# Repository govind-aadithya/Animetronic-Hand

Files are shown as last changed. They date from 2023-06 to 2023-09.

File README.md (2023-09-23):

# Animatronic-Hand

## Objective
Gesture-controlled animatronic hand intended to perform teleoperation. 

The project was developed as a proof of concept for teleoperation using gesture tracking.

## Purpose
This was a concept developed for a Hardware Hackathon "Byte into Hardware" held at NJIT in April'23. The theme of the hackathon was to empower accessibility for differently abled. 

## Hardware
1. 3D Printed Animatronic Hand
2. Tower Pro Servos (SG90)
3. Logitech Web Cam
4. Arduino
5. IMU - MPU6050.

## Approach
The project uses Computer Vision to perform gesture tracking and interpret the gestures made by the user. This is then sent to the Arduino as actuation commands to make the Animatronic hand replicate the gesture.
To complete the loop, we used a Logitech webcam to provide a video feed to the user by coupling it with servos for yaw control. The command to the yaw control is given via an IMU that tracks the yaw of the user's head.

### Architecture
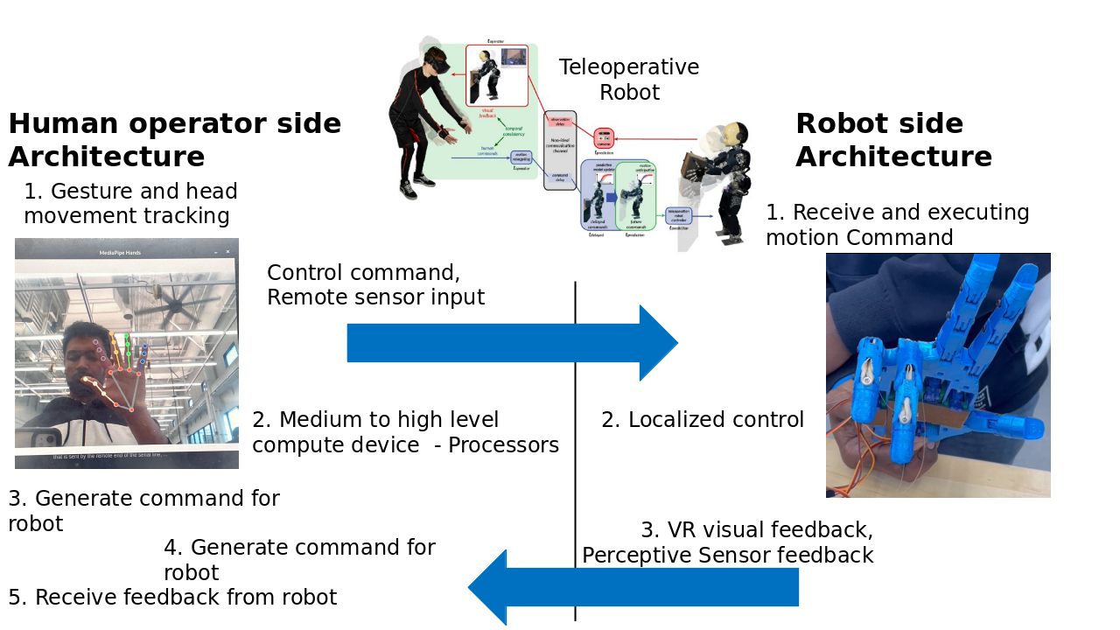
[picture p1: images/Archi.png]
Architecture


## Animatronic Hand
The .stp file was developed and printed on an Ultimaker 3D Printer. Since on slicing the file, the print duration was over 48hrs, the print was spit in several parts and printed on multiple printers.
The files can be found in the [CAD folder](./CAD) of the project.

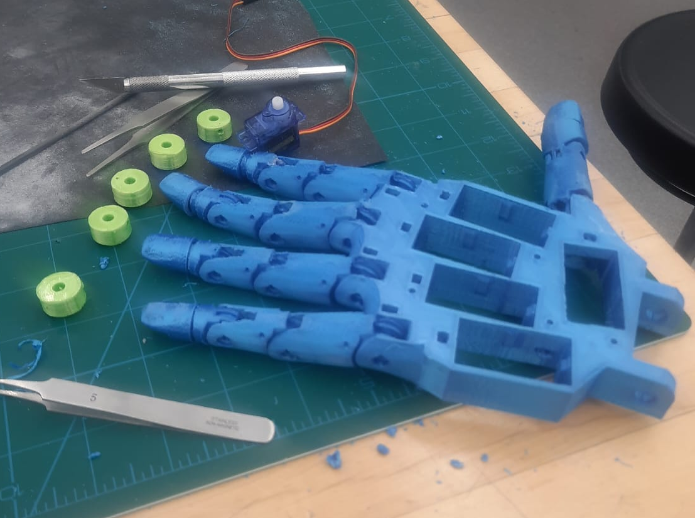
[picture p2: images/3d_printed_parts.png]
3D Printed Parts


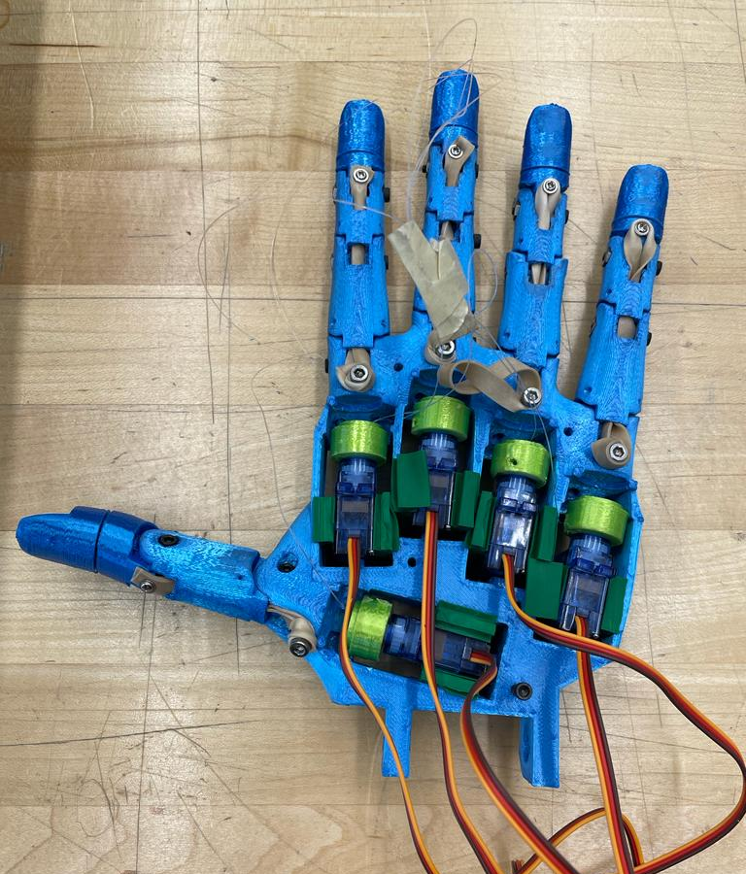
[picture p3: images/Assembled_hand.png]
Final Assembly


## Gesture Tracking and Control
In order to track the gesture, the project leverages the [Mediapipe](https://developers.google.com/mediapipe/solutions/vision/hand_landmarker/python) package to locate the keypoints. Once the keypoints are obtained, we perform a calibration to eliminate scaling and map the movements of the keypoints from the fingers to obtain the degree of actuation. This is then sent to Arduino as servo actuation commands to actuate the Animatronic hand.

Gesture Tracking

The [video](https://www.youtube.com/watch?v=KrDJfOwzTok) shows the tracking along with the calibration process and servo command generation.

The complete video showing the process from start to finish can be found [here](https://youtu.be/Sb4F23Tmr3c?si=_DHQ8RgZvzNWH9Fh).

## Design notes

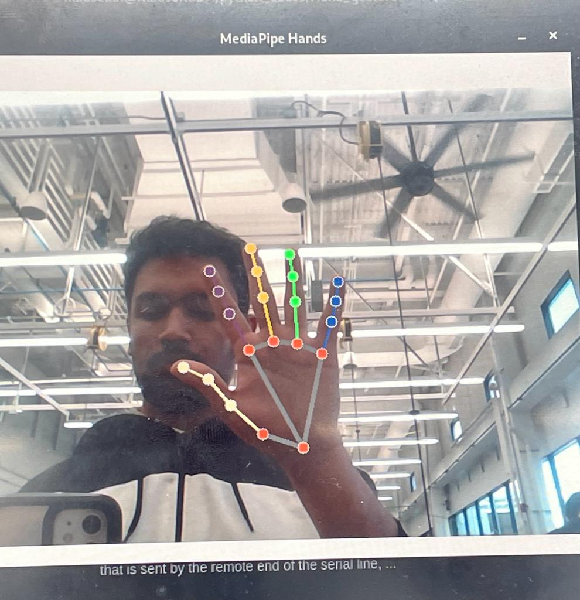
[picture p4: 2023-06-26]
images/Gesture_Tracking.png

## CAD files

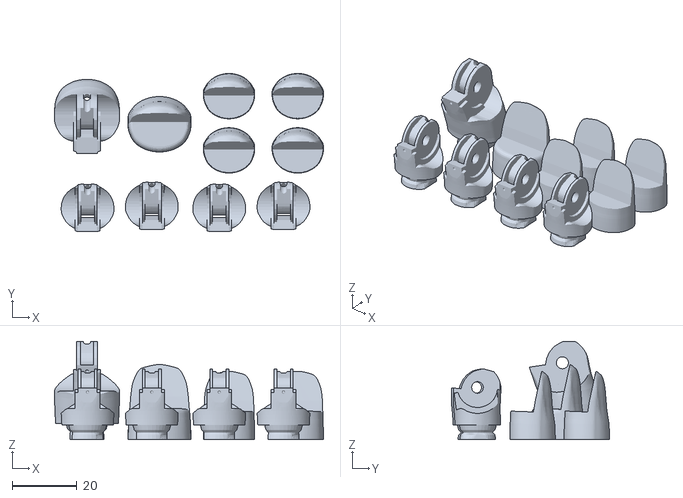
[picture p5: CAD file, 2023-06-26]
CAD/finger nail.stl
82.9 x 48.7 x 30.2

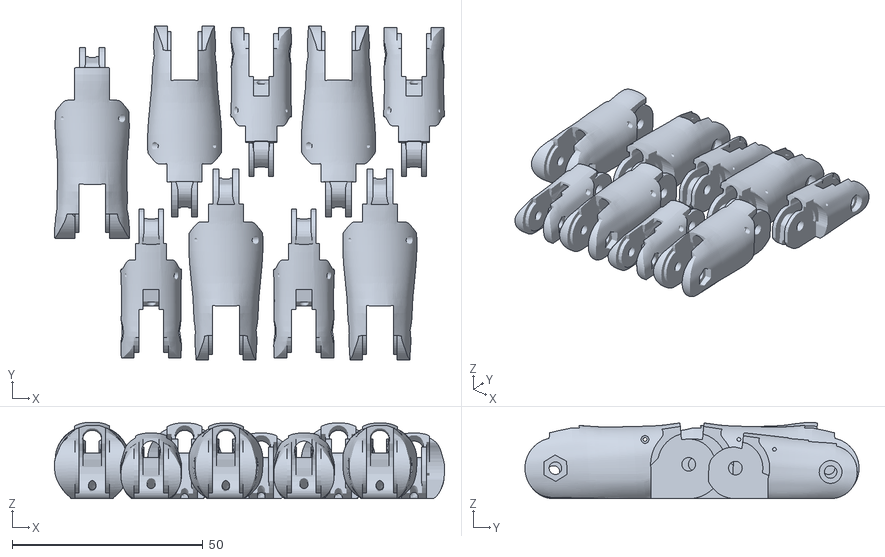
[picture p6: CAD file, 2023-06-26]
CAD/fingers.stl
102.3 x 87.7 x 20.0

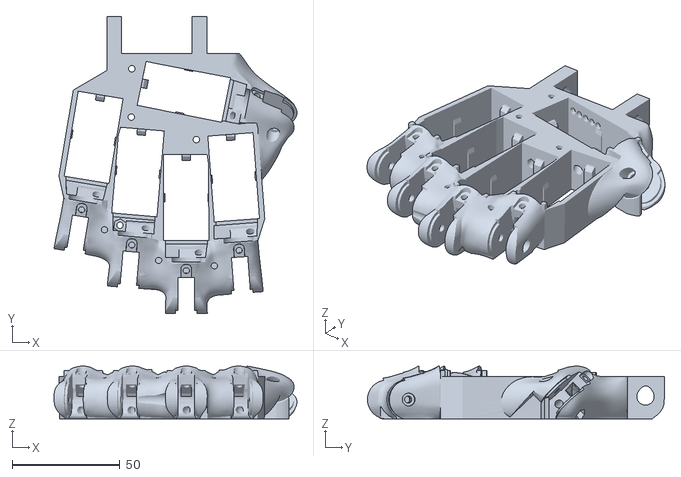
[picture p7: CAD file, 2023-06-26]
CAD/Wrist.stl
112.6 x 137.7 x 24.5

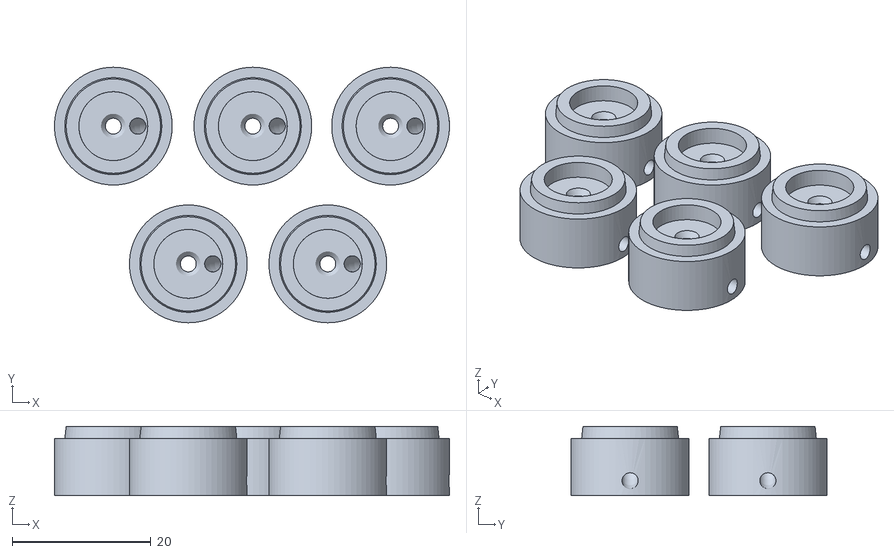
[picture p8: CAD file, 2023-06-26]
CAD/motor_pully.stl
57.0 x 36.9 x 10.0

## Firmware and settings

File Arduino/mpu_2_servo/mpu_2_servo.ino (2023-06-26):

#include <Wire.h>
#include <Servo.h>
#include <MPU6050.h>

MPU6050 mpu;
Servo servo;

void setup() {
  Wire.begin();
  Serial.begin(9600);
  mpu.initialize();
  servo.attach(9); // Connect the servo signal wire to pin 9
}

void loop() {
  // Read yaw angle from MPU-6050
  int16_t gyroYaw = mpu.getRotationY();

  // Convert yaw angle to servo position
  int servoPos = map(gyroYaw, -32768, 32767, 0, 180);

  // Constrain servo position within range
  servoPos = constrain(servoPos, 0, 180);

  // Set servo position
  servo.write(servoPos);

  // Print yaw angle and servo position
  Serial.print("Yaw angle: ");
  Serial.print(gyroYaw);
  Serial.print("  Servo position: ");
  Serial.println(servoPos);

  delay(10); // Adjust delay as needed
}

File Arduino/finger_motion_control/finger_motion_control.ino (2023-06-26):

// str(mapped[0][0]) + ',' + str(mapped[1][0]) + ',' + str(mapped[2][0]) + ',' + str(mapped[3][0]) + ',' + str(mapped[4][0]) + '\n'
// To collect the data from the computer
// Decode the string
// send it to servo 

#include <Servo.h>

Servo servo[5];

void setup() {
  // put your setup code here, to run once:
  Serial.begin(9600);
  servo[0].attach( 9);
  servo[1].attach(10);
  servo[2].attach(11);
  servo[3].attach(12);
  servo[4].attach(13);
}

String digit[5];
int delimiter[5];

void loop() {
  // put your main code here, to run repeatedly:
  if (Serial.available() > 2){
    String readString = Serial.readStringUntil('\n');
    
    int j = readString.indexOf('\\');
    readString.remove(j);
    
    //Serial.println(readString+String(j));
    delimiter[0] = readString.indexOf(',');
    digit[0] = readString.substring(0,delimiter[0]);
    servo[0].write(digit[0].toInt());
    for(int i = 1; i <= 4; i++){
      delimiter[i] = readString.indexOf(",",delimiter[i-1]+1);
      Serial.println(delimiter[i]);
      digit[i] = readString.substring(delimiter[i-1]+1,delimiter[i]);
      servo[i].write(digit[i].toInt());
    }
	//Serial.println(String(digit[0])+" "+String(digit[1])+" "+String(digit[2])+" "+String(digit[3])+" "+String(digit[4]));
  }
}

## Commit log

2023-06-26 Arduino Code Updated
2023-06-26 CAD Files
    [Wrist.stl, finger nail.stl, fingers.stl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]
2023-06-26 Design Updated
    [Wrist.stl, finger nail.stl, fingers.stl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]
